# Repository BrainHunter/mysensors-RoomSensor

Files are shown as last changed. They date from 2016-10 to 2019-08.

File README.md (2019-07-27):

# mysensors-RoomSensor
Firmware for the RoomSensor

To build this Firmware you need this Arduino Packages:
* mysensors v2.0
* DHT
* SparkFunBME280
* SI7021

Select the Board "NK-Tronic RoomSensor" and Processor: "ATmega328 (3.3V, 8Mhz RC)"

Install the firmware on the board with a ISP programmer like the STK500 or USBasp.

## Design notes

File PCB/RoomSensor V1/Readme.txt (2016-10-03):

First version PCB. This one has some Errors:

- Missing connection in the switching supply
- Wrong footprint for the AP3015. (Too small)

	--> PCB's are usable with some solder skills ;-)

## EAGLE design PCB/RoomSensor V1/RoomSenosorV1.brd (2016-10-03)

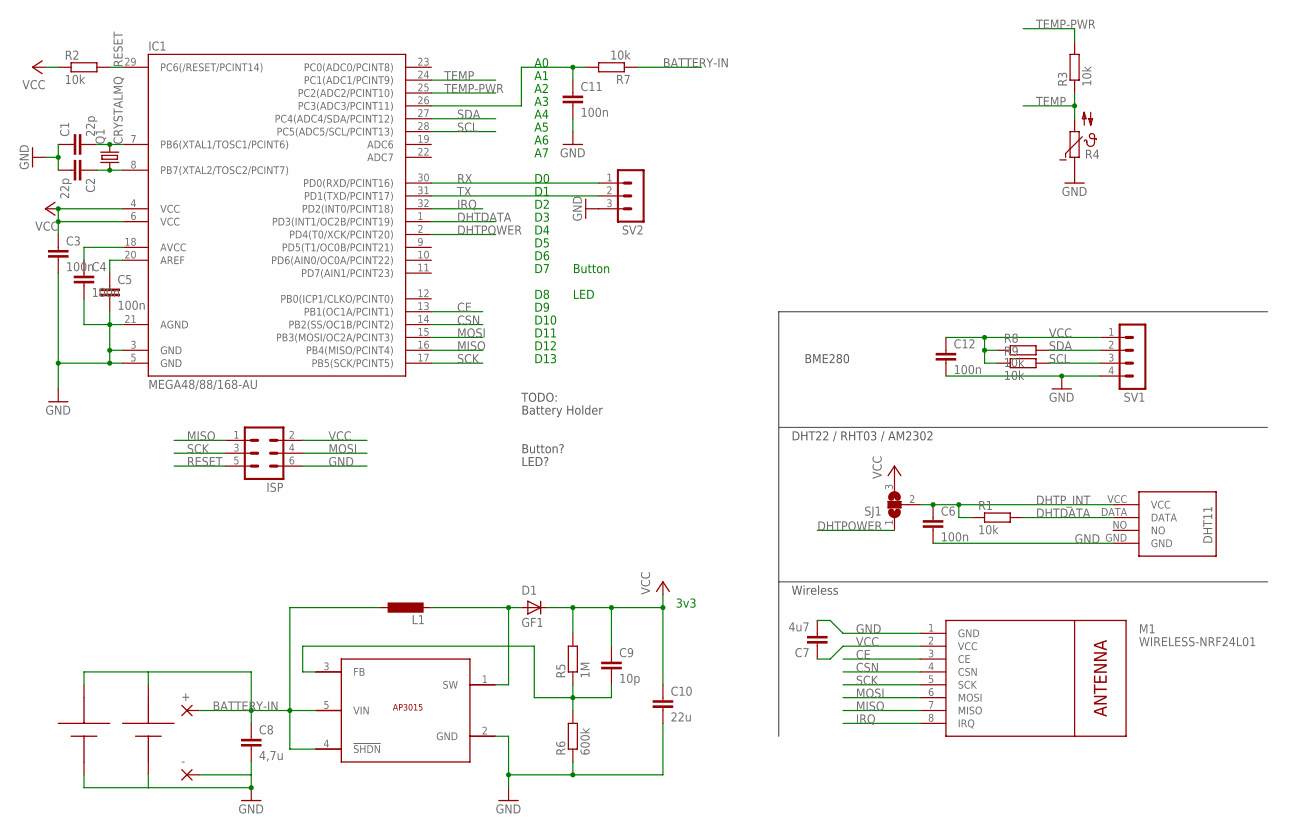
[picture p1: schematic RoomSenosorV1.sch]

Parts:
+: 1,6/0,8
-: 1,6/0,8
C1, C2: 22p; C0805
C3, C4, C5, C6, C11, C12: 100n; C0805
C7: 4u7; C0805
C8: 4,7u; C0805
C9: 10p; C0805
C10: 22u; C1206
D1: GF1; SMA-DO214AC
IC1: MEGA48/88/168-AU; TQFP32-08
ISP: MA03-2
L1: L-EUL2825P; L2825P
M1: WIRELESS-NRF24L01
Q1: CRYSTALMQ; MQ
R1, R2, R3, R7, R8, R9: 10k; R0805
R4: NTC640; P640
R5: 1M; R0805
R6: 600k; R0805
SJ1: SJ2W; SJ_2
SV1: MA04-1
SV2: MA03-1
U$1: AP3015/A; SOT353
U$2: DHT11
U$3: MIGNON_1
U$4: RS_279-4959

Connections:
BATTERY-IN: +.1, C8.1, L1.1, R7.1, U$1.4 (!SHDN), U$1.5 (VIN), U$3.POS, U$4.POS
BATTERY-IN-LP: C11.1, IC1.26 (PC3(ADC3/PCINT11)), R7.2
CE: IC1.13 (PB1(OC1A/PCINT1)), M1.3 (CE)
CSN: IC1.14 (PB2(SS/OC1B/PCINT2)), M1.4 (CSN)
DHTDATA: IC1.1 (PD3(INT1/OC2B/PCINT19)), R1.2, U$2.DATA
DHTPOWER: IC1.2 (PD4(T0/XCK/PCINT20)), SJ1.1
DHTP_INT: C6.1, R1.1, SJ1.2, U$2.VCC
GND: -.1, C1.1, C2.2, C3.2, C4.2, C5.2, C6.2, C7.2, C8.2, C10.2, C11.2, C12.2, IC1.3 (GND), IC1.5 (GND), IC1.21 (AGND), ISP.6, M1.1 (GND), R4.1, R6.1, SV1.4, SV2.3, U$1.2 (GND), U$2.GND, U$3.NEG, U$4.NEG
IRQ: IC1.32 (PD2(INT0/PCINT18)), M1.8 (IRQ)
MISO: IC1.16 (PB4(MISO/PCINT4)), ISP.1, M1.7 (MISO)
MOSI: IC1.15 (PB3(MOSI/OC2A/PCINT3)), ISP.4, M1.6 (MOSI)
unnamed: C2.1, IC1.8 (PB7(XTAL2/TOSC2/PCINT7)), Q1.P1 (1)
unnamed: C1.2, IC1.7 (PB6(XTAL1/TOSC1/PCINT6)), Q1.P3 (2)
unnamed: C9.2, R5.1, R6.2, U$1.3 (FB)
unnamed: C5.1, IC1.20 (AREF)
unnamed: C4.1, IC1.18 (AVCC)
unnamed: D1.A, L1.2, U$1.1 (SW)
RESET: IC1.29 (PC6(/RESET/PCINT14)), ISP.5, R2.2
RX: IC1.30 (PD0(RXD/PCINT16)), SV2.1
SCK: IC1.17 (PB5(SCK/PCINT5)), ISP.3, M1.5 (SCK)
SCL: IC1.28 (PC5(ADC5/SCL/PCINT13)), R9.2, SV1.3
SDA: IC1.27 (PC4(ADC4/SDA/PCINT12)), R8.2, SV1.2
TEMP: IC1.24 (PC1(ADC1/PCINT9)), R3.1, R4.2
TEMP-PWR: IC1.25 (PC2(ADC2/PCINT10)), R3.2
TX: IC1.31 (PD1(TXD/PCINT17)), SV2.2
VCC: C3.1, C7.1, C9.1, C10.1, C12.1, D1.K (C), IC1.4 (VCC), IC1.6 (VCC), ISP.2, M1.2 (VCC), R2.1, R5.2, R8.1, R9.1, SJ1.3, SV1.1

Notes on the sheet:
D10
D11
D12
D13
3v3
LED
Button
Wireless
DHT22 / RHT03 / AM2302
TODO:
Battery Holder
Button?
LED?
BME280

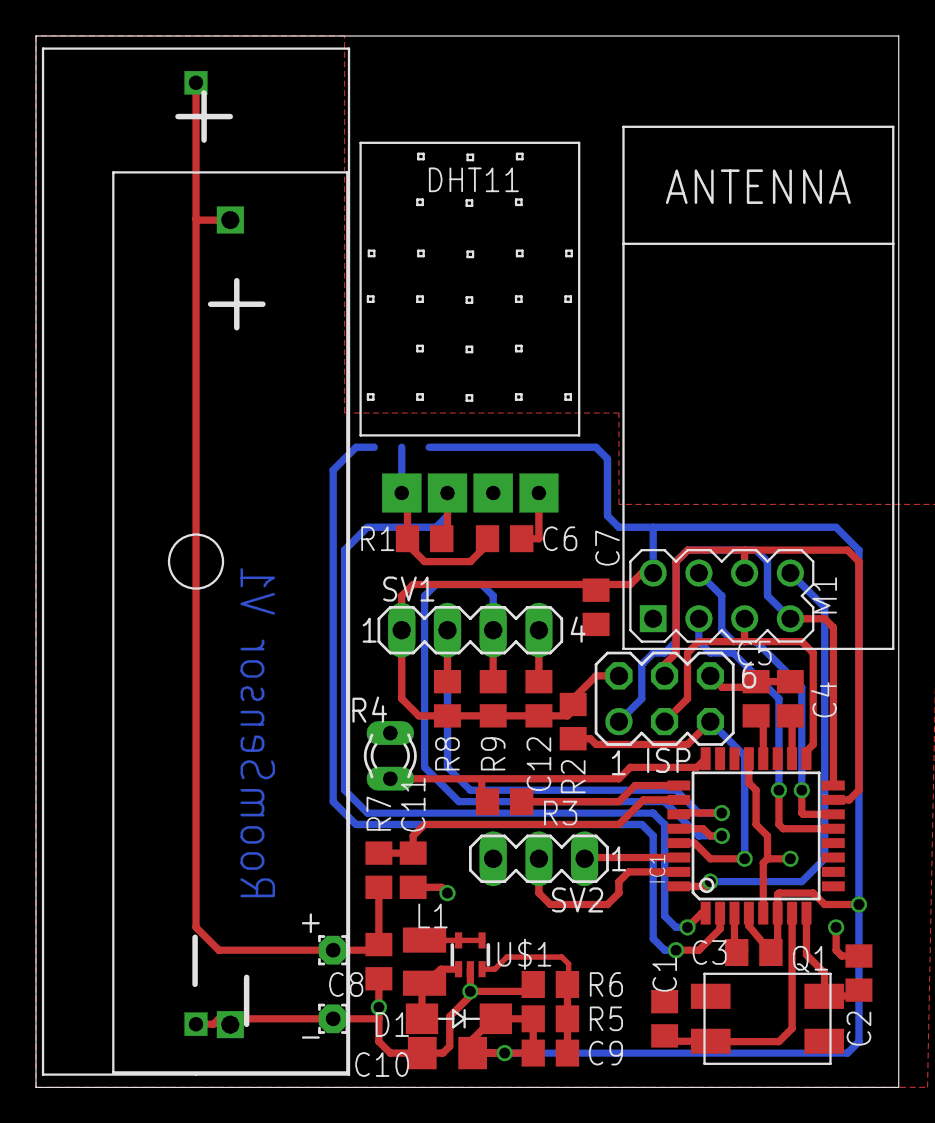
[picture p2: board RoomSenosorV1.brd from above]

Board: 2 copper layers, 47.9 x 58.4 mm, 36 parts (1 on the bottom side), 26 nets.

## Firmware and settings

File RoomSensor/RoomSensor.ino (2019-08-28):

// MySensors Config
// Enable debug prints to serial monitor
// #define MY_DEBUG 

// Enable and select radio type attached
#define MY_RADIO_NRF24
//#define MY_RADIO_RFM69
#define MY_RF24_CE_PIN 9    // Radio specific settings for RF24
#define MY_RF24_CS_PIN 10   // Radio specific settings for RF24 

// ------- Includes -------
#include <MySensors.h>
#include "arduino.h"
#include <DHT.h>
#include "SparkFunBME280.h"
#include <SI7021.h>

// -------  Configuration Start ------- 
  // Sensors configuration:
  // Comment in all sensors connected:
  //#define HAS_NTC
  #define HAS_LDR
  //#define HAS_BME280
  #define HAS_SI7021
  //#define HAS_DHT

  // How long should the sensor sleep ?
  #define SLEEP_TIME (2UL*60UL*1000UL)    // 2min * 60sec * 1000ms
  //#define SLEEP_TIME (2UL*1000UL)           // 2sec * 1000ms

// -------  Configuration End -------


#define VERSION 1.3

#define xstr(a) str(a)
#define str(a) #a

// BME280 related:
BME280 bmeSensor;

// SI7021 related:
SI7021 SI7021Sensor;

// DHT Sensor related:
#define HUMIDITY_SENSOR_DIGITAL_PIN 3
DHT dht;
boolean metric = true; 

// Sensor ID's
#define DHT_Temp_ID 1
#define DHT_Humidity_ID 2
#define NTC_Temp_ID 3        // depending on ntc
#define LDR_Light_ID 3       // or ldr
#define BME_Temp_ID 4
#define BME_Humidity_ID 5
#define BME_Pressure_ID 6
#define SI_Temp_ID 7
#define SI_Humidity_ID 8

// mysensors related:
//MyMessage msg(Moisture_ID,V_LEVEL);
#ifdef HAS_DHT
  MyMessage DHTTempMsg(DHT_Temp_ID,V_TEMP);
  MyMessage DHTHumMsg(DHT_Humidity_ID,V_HUM);
#endif 
#ifdef HAS_NTC
  MyMessage NTCTempMsg(NTC_Temp_ID,V_TEMP);
#endif
#ifdef HAS_LDR
  MyMessage LDRLightMsg(LDR_Light_ID,V_LIGHT_LEVEL);
#endif
#ifdef HAS_BME280
  MyMessage BMETempMsg(BME_Temp_ID,V_TEMP);
  MyMessage BMEHumMsg(BME_Humidity_ID,V_HUM);
  MyMessage BMEBaroMsg(BME_Pressure_ID,V_PRESSURE);
#endif
#ifdef HAS_SI7021
  MyMessage SITempMsg(SI_Temp_ID,V_TEMP);
  MyMessage SIHumMsg(SI_Humidity_ID,V_HUM);
#endif


// local defs
unsigned long timediff(unsigned long t1, unsigned long t2);
#ifdef HAS_NTC
int NTC_ADC2Temperature(unsigned int adc_value);
#endif
int getBatteryLevel(void);
extern volatile unsigned long timer0_millis;

void before() {
  // run code before mysensors init
  Serial.begin(115200);
  while(!Serial)
  {
   ; // wait for serial port to connect. Needed for native USB
  }
  Serial.print("Serial init\r\n"); 
  
}

void setup() {
  // put your setup code here, to run once:

  // mysensors presentation:
  presentation();
  
#ifdef HAS_DHT
  // ------ DHT11 init -----
  //Pin 4 is the power source for the DHT
  pinMode(4,OUTPUT);
  digitalWrite(4,HIGH);
  // 
  dht.setup(HUMIDITY_SENSOR_DIGITAL_PIN); 
  dht.getTemperature();
  delay(2000);
  Serial.print("DHT init\r\n");
#endif

#if defined(HAS_NTC) || defined(HAS_LDR)
  // ---- NTC / LDR Init ----
  pinMode(A1,INPUT);
  pinMode(A2,OUTPUT);
  digitalWrite(A2,LOW);
  Serial.print("NTC/LDR init\r\n");
#endif

#ifdef HAS_BME280
  // ------ BME280 Init ------
  bmeSensor.settings.commInterface = I2C_MODE;
  bmeSensor.settings.I2CAddress = 0x77;
  bmeSensor.settings.runMode = 3; //Normal mode
  bmeSensor.settings.tStandby = 0;
  bmeSensor.settings.filter = 0;
  bmeSensor.settings.tempOverSample = 1;
  bmeSensor.settings.pressOverSample = 1;
  bmeSensor.settings.humidOverSample = 1;
  Serial.println(bmeSensor.begin(), HEX);
  Serial.print("Displaying ID, reset and ctrl regs\n");
  Serial.print("ID(0xD0): 0x");
  Serial.println(bmeSensor.readRegister(BME280_CHIP_ID_REG), HEX);
  Serial.print("Reset register(0xE0): 0x");
  Serial.println(bmeSensor.readRegister(BME280_RST_REG), HEX);
  Serial.print("ctrl_meas(0xF4): 0x");
  Serial.println(bmeSensor.readRegister(BME280_CTRL_MEAS_REG), HEX);
  Serial.print("ctrl_hum(0xF2): 0x");
  Serial.println(bmeSensor.readRegister(BME280_CTRL_HUMIDITY_REG), HEX);

  Serial.print("\n\n");
  
  Serial.print("BME280 init\r\n"); 
#endif

  
#ifdef HAS_SI7021
  SI7021Sensor.begin();
  Serial.println("SI7021 init"); 
#endif
  
  //  ---- Battery Input ----
  pinMode(A3,INPUT);
  
} // END void setup() 


#ifdef HAS_NTC
  #define NTC_TEXT " NTC"
#else
 #define NTC_TEXT ""
#endif

#ifdef HAS_LDR 
 #define LDR_TEXT " LDR" 
#else
 #define LDR_TEXT ""
#endif 

#ifdef HAS_BME280 
  #define BME_TEXT " BME" 
#else
 #define BME_TEXT ""
#endif 

#ifdef HAS_SI7021 
 #define SI_TEXT " SI" 
#else
 #define SI_TEXT ""
#endif 

#ifdef HAS_DHT 
 #define DHT_TEXT " DHT" 
#else
 #define DHT_TEXT ""
#endif 
 
#define NodeName "Room Sensor " NTC_TEXT LDR_TEXT BME_TEXT SI_TEXT DHT_TEXT
  
void presentation()  
{
  #ifdef MY_DEBUG
  sendSketchInfo(NodeName, xstr(VERSION) "D");  
  #else
  sendSketchInfo(NodeName, xstr(VERSION)); 
  #endif
  
  Serial.println("Sketch Info");
  
  //register the sensors to the gateway
  #ifdef HAS_DHT
  present(DHT_Temp_ID , S_TEMP);
  present(DHT_Humidity_ID , S_HUM);
  #endif

  #ifdef HAS_NTC
  present(NTC_Temp_ID , S_TEMP);
  #endif
  
  #ifdef HAS_LDR
  present(LDR_Light_ID , S_LIGHT_LEVEL);
  #endif
  
  #ifdef HAS_BME280
  present(BME_Temp_ID , S_TEMP);
  present(BME_Humidity_ID , S_HUM);
  present(BME_Pressure_ID , S_BARO);
  #endif

  #ifdef HAS_SI7021
  present(SI_Temp_ID , S_TEMP);
  present(SI_Humidity_ID , S_HUM);
  #endif
  
} // END void presentation()  

void loop() {
  float temp;
  float humidity;
  float pressure;

  Serial.println("------ Loop begin -------");

  // NTC | LDR
  digitalWrite(A2, HIGH);   // Power ON NTC / LDR

#ifdef HAS_NTC
  int ntc = analogRead(A1);
  temp = NTC_ADC2Temperature(ntc)/10;
  Serial.print("ntc adc: ");
  Serial.println(ntc);
  Serial.print("ntc Temp: ");
  Serial.println(temp);
  //send the measured value
  send(NTCTempMsg.set(temp,1));
#endif
#ifdef HAS_LDR
  Serial.println("ldr:");
  int ldr = analogRead(A1);
  Serial.println(ldr);
  //send the measured value
  send(LDRLightMsg.set(ldr, 1) );
#endif
  
  digitalWrite(A2, LOW);  // Power OFF NTC / LDR

  // Send Battery Level:
  sendBatteryLevel(getBatteryLevel());
  
  // DHT
#ifdef HAS_DHT
  temp = dht.getTemperature();
  if (isnan(temp)) {
    Serial.println("Failed reading temperature from DHT");
  }else{
    if (!metric) {
      temp = dht.toFahrenheit(temp);
    }
    send(DHTTempMsg.set(temp, 1));
    Serial.print("DHT Temp: ");
    Serial.println(temp); 
  }
  humidity = dht.getHumidity();
  if (isnan(humidity)) {
      Serial.println("Failed reading humidity from DHT");
  }
  else{
    send(DHTHumMsg.set(humidity, 1));
    Serial.print("DHT Hum: ");
    Serial.println(humidity);
  }
#endif

  // BME280
#ifdef HAS_BME280
  {
  temp = bmeSensor.readTempC(); 
  send(BMETempMsg.set(temp, 1));
  Serial.print("Temperature: ");
  Serial.print(temp, 2);
  Serial.println(" degrees C");
 
  Serial.print("Temperature: ");
  Serial.print(bmeSensor.readTempF(), 2);
  Serial.println(" degrees F"); 
    
  pressure = bmeSensor.readFloatPressure();
  send(BMEBaroMsg.set(pressure, 1));
  Serial.print("Pressure: ");
  Serial.print(pressure, 2);
  Serial.println(" Pa");
    
  Serial.print("Altitude: ");
  Serial.print(bmeSensor.readFloatAltitudeMeters(), 2);
  Serial.println("m");

  Serial.print("Altitude: ");
  Serial.print(bmeSensor.readFloatAltitudeFeet(), 2);
  Serial.println("ft"); 

  humidity = bmeSensor.readFloatHumidity();
  send(BMEHumMsg.set(humidity, 1));
  Serial.print("%RH: ");
  Serial.print(humidity, 2);
  Serial.println(" %");
  
  Serial.println();
  }
#endif

  // SI7021
#ifdef HAS_SI7021
  si7021_env data = SI7021Sensor.getHumidityAndTemperature();
  temp = ((float)data.celsiusHundredths) / 100; 
  send(SITempMsg.set(temp, 1));
  Serial.print("SI Temp: ");
  Serial.println(temp);
  
  humidity = data.humidityPercent;
  send(SIHumMsg.set(humidity, 1));
  Serial.print("SI HUM: ");
  Serial.println(humidity);
#endif

  // ----- go into power down mode: -----
  Serial.println("Go to Sleep !");
  sleep(SLEEP_TIME);  

  // adjust the value for millis() after sleep:
  uint8_t oldSREG = SREG;
  cli();
  timer0_millis += SLEEP_TIME;  
  SREG = oldSREG;
}

unsigned long timediff(unsigned long t1, unsigned long t2)
{
    signed long d = (signed long)t1 - (signed long)t2;
    if(d < 0) d = -d;
    return (unsigned long) d;
}


#ifdef HAS_NTC
//http://www.sebulli.com/ntc/index.php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
//https://www.amazon.de/SODIAL-Stueck-Temperaturmessung-Thermistoren-MF52-103/dp/B00HUHC4UU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

/**
* Die NTC Tabelle, bestehend aus 65 Temperaturstützpunkten.
* Einheit:0.1 °C
*
*/
int NTC_table[65] = {
  1921, 1607, 1293, 1127, 1016, 933, 866, 811, 
  763, 722, 685, 652, 621, 593, 567, 543, 520, 
  498, 477, 458, 439, 421, 403, 386, 370, 354, 
  338, 323, 308, 293, 278, 264, 250, 236, 222, 
  208, 194, 181, 167, 153, 139, 125, 111, 97, 
  83, 68, 53, 37, 22, 5, -11, -29, -47, -66, 
  -87, -108, -132, -157, -186, -218, -256, 
  -302, -364, -460, -556
};
 

/**
* \brief    Konvertiert das ADC Ergebnis in einen Temperaturwert.
*
*           Mit p1 und p2 wird der Stützpunkt direkt vor und nach dem
*           ADC Wert ermittelt. Zwischen beiden Stützpunkten wird linear
*           interpoliert. Der Code ist sehr klein und schnell.
*           Es wird lediglich eine Ganzzahl-Multiplikation verwendet.
*           Die Division kann vom Compiler durch eine Schiebeoperation.
*           ersetzt werden.
*
*           Im Temperaturbereich von -30°C bis 50°C beträgt der Fehler
*           durch die Verwendung einer Tabelle 0.144°C
*
* \param    adc_value  Das gewandelte ADC Ergebnis
* \return              Die Temperatur in 0.1 °C
*
*/
int NTC_ADC2Temperature(unsigned int adc_value){
 
  int p1,p2;
  /* Stützpunkt vor und nach dem ADC Wert ermitteln. */
  p1 = NTC_table[ (adc_value >> 4)  ];
  p2 = NTC_table[ (adc_value >> 4)+1];
 
  /* Zwischen beiden Punkten linear interpolieren. */
  return p1 - ( (p1-p2) * (adc_value & 0x000F) ) / 16;
};

#endif

// ------------- BATTERY --------------

#define BAT_AVG_NUM 8
#define BAT100  1500
#define BAT0    950

int ReadBandgap()
{
    uint8_t low, high;
    uint8_t reference = DEFAULT;
    uint8_t pin = 14;
    ADMUX = (reference << 6) | (pin);

    // settle
    delayMicroseconds(200);    
    // start the conversion
    //sbi(ADCSRA, ADSC);
    ADCSRA |= 1 << ADSC;
    // ADSC is cleared when the conversion finishes
    while (bit_is_set(ADCSRA, ADSC));

    low  = ADCL;
    high = ADCH;

    return (high << 8) | low;
}

int getBatteryLevel()
{
  // Read the adc 
  uint32_t bandgap = 341; // ReadBandgap(); // 1.1 Voltage value
  
  //for(int i = 0; i < 2; i++)
  //{

    bandgap = ReadBandgap();
    Serial.print("Bg adc: ");
    Serial.println(bandgap);
  //}  
  
  //Serial.print("Bg adc: ");
  //Serial.println(bandgap);

  uint32_t ArefVoltage = (1100UL * 1024UL) / (bandgap);
  Serial.print("Aref: ");
  Serial.println(ArefVoltage);
  
  uint32_t adc = 0; 
  
  for(int i = 0; i < BAT_AVG_NUM; i++){
    uint32_t temp = analogRead(A3);
    //Serial.print("temp: ");
    //Serial.println(temp);
    adc += temp;
  }
  Serial.print("Bat adc: ");
  Serial.println(adc);

  // Calculate the voltage in mV
  // Reference is 3.3V 
  //uint32_t Voltage = (330 * adc) / (1024*BAT_AVG_NUM);
  // 1.1V bandgap reference calibration
  uint32_t Voltage = (1100UL * adc) / (bandgap * BAT_AVG_NUM);
  Serial.print("Voltage [mV]: ");
  Serial.println(Voltage);

  // Clamp at the Borders
  if(Voltage < BAT0) Voltage = BAT0;
  if(Voltage > BAT100) Voltage = BAT100;
  
  // calculate level
  // let 1.5V be 100%
  // let 0.8V be 0%
  uint32_t level = (100*(Voltage-BAT0))/(BAT100-BAT0);
  Serial.print("BAT LEVEL [%]: ");
  Serial.println(level);

  return (int)level;
}

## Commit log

2016-10-03 Added PCB version 1 Files
    [RoomSenosorV1.brd, RoomSenosorV1.sch]
2016-10-09 renamed the ino file Added the Board definition
2019-08-28 Changed 0% battery voltage from 0.8V to 0.95V

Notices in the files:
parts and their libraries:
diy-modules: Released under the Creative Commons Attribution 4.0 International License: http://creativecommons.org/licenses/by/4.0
